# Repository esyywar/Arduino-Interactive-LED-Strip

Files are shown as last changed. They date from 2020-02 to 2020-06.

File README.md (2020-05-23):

# Arduino-Interactive-LED-Strip

This project features the hardware and software development of a multi-function LED strip controller!

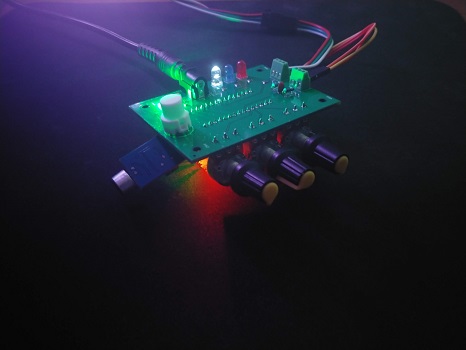
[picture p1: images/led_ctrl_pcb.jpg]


The light strip has 3 different modes:
1. HSV Static Colour Set
2. Patterned Light Show
3. Music Wave Visualizer

User can switch between the 3 modes by pushing a button. In each mode, parameters can be adjusted by turning the 3 potentiometer knobs.

Here are the functions of each knob in each mode:

| Mode  | Knob 1 | Knob 2 | Knob 3 |
| --- | ---- | ---- | ---- |
| HSV Static Colour Set | Hue | Saturation | Brightness |
| Patterned Light Show | Colour Pattern | Scramble Effect | Brightness |
| Music Wave Visualizer | Wave Point Source | Volume Sensitivity | Brightness |

Folders in the repository are organized as follows:

## Firmware

The arduino nano code for this controller. Simple code using FastLED library and interrupts for switching modes.

## PCB-Design

PCB designed in KiCAD to recreate this controller
Can be assembled for about 40 - 80 CAD depending on how much you spend for PCB fabrication and the LED strip.

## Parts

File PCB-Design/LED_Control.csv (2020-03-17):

Comment | Designator | Footprint | LCSC | LCSC
Arduino_Nano_v3.x | A1 | Module:Arduino_Nano
0.1uF | C1,C2 | Capacitor_SMD:C_0603_1608Metric |  | C14663
100uF | C3 | Capacitor_Tantalum_SMD:CP_EIA-3528-15_AVX-H |  | C16133
0.1uF | C4 | Capacitor_THT:C_Disc_D3.4mm_W2.1mm_P2.50mm
BLUE LED | D1 | LED_THT:LED_D5.0mm
RED LED | D2 | LED_THT:LED_D5.0mm
WHITE LED | D3 | LED_THT:LED_D5.0mm
GREEN LED | D4 | LED_SMD:LED_0805_2012Metric |  | C63855
5V 5A Power | J1 | PJ-002AH:CUI_PJ-002AH
TO WS2812B LED STRIP | J2 | TerminalBlock_TE-Connectivity:TerminalBlock_TE_282834-3_1x03_P2.54mm_Horizontal
Sound Sensor | J3 | TerminalBlock_TE-Connectivity:TerminalBlock_TE_282834-3_1x03_P2.54mm_Horizontal
10k | R1 | Resistor_SMD:R_0805_2012Metric |  | C17414
330 | R5,R3,R4,R2 | Resistor_SMD:R_0805_2012Metric |  | C17630
300 | R6 | Resistor_SMD:R_0805_2012Metric |  | C17617
100k | R7 | Resistor_THT:R_Axial_DIN0204_L3.6mm_D1.6mm_P5.08mm_Horizontal
10k | R8 | Resistor_THT:R_Axial_DIN0204_L3.6mm_D1.6mm_P5.08mm_Horizontal
100k | RV1,RV3,RV2 | Custom Footprint:Potentiometer_4mm_Pitch
SW_Push_Dual | SW1 | Custom Footprint:Push_Button_Switch

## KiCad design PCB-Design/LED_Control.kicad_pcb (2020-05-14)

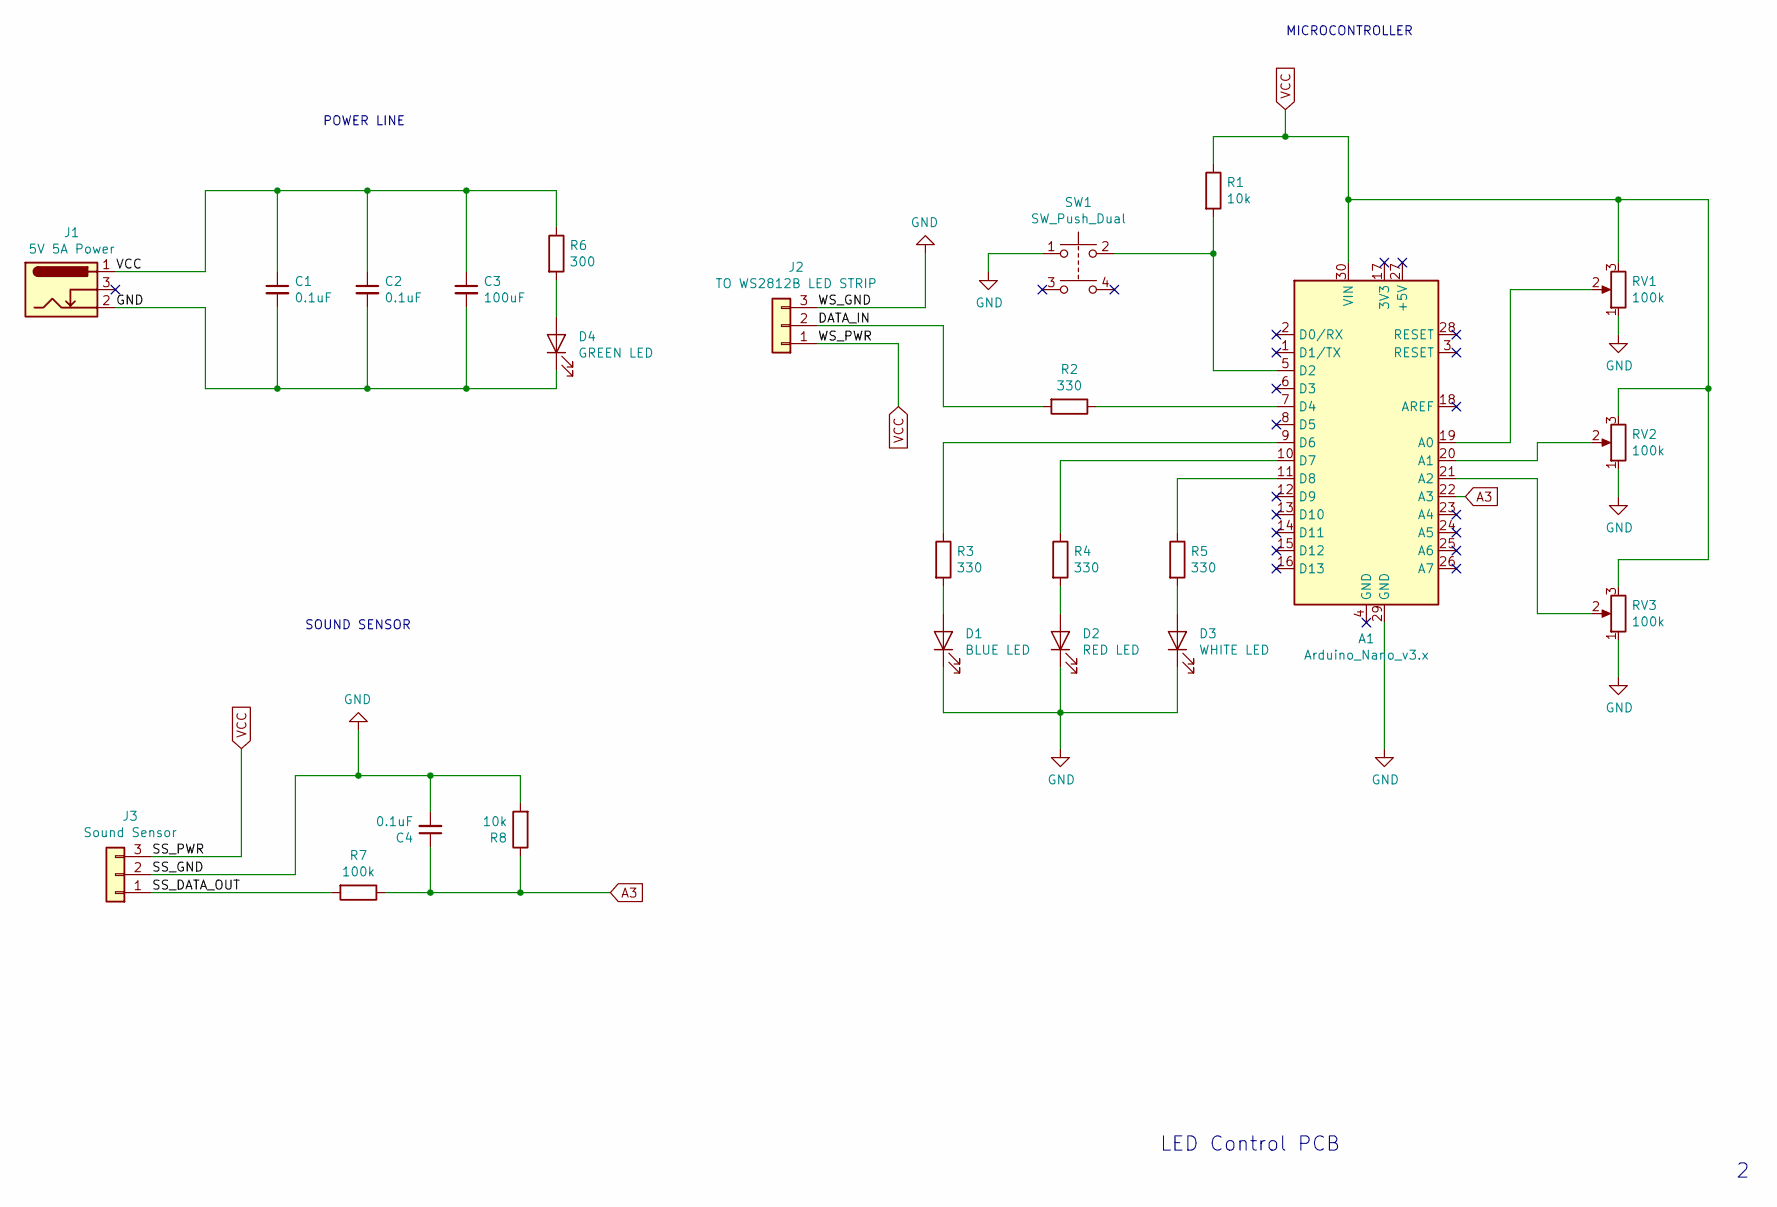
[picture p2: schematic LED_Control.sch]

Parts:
A1: Arduino_Nano_v3.x; Arduino_Nano
C1: 0.1uF; C_0603_1608Metric; LCSC C14663
C2: 0.1uF; C_0603_1608Metric; LCSC C15849
C3: 100uF; CP_EIA-3528-15_AVX-H; LCSC C16133
C4: 0.1uF; C_Disc_D3.4mm_W2.1mm_P2.50mm
D1: BLUE LED; LED_D5.0mm
D2: RED LED; LED_D5.0mm
D3: WHITE LED; LED_D5.0mm
D4: GREEN LED; LED_0805_2012Metric; LCSC C63855
J1: 5V 5A Power; CUI_PJ-002AH
J2: TO WS2812B LED STRIP; TerminalBlock_TE_282834-3_1x03_P2.54mm_Horizontal
J3: Sound Sensor; TerminalBlock_TE_282834-3_1x03_P2.54mm_Horizontal
R1: 10k; R_0805_2012Metric; LCSC C17414
R2, R3, R4, R5: 330; R_0805_2012Metric; LCSC C17630
R6: 300; R_0805_2012Metric; LCSC C17617
R7: 100k; R_Axial_DIN0204_L3.6mm_D1.6mm_P5.08mm_Horizontal
R8: 10k; R_Axial_DIN0204_L3.6mm_D1.6mm_P5.08mm_Horizontal
RV1, RV2, RV3: 100k; Potentiometer_5.08mm_Pitch
SW1: SW_Push_Dual; Push_Button_Switch

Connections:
/DATA_IN: J2.2, R2.2
/SS_DATA_OUT: J3.1, R7.2
A3: A1.22 (A3), C4.1, R7.1, R8.1
GND: A1.29 (GND), C1.2, C2.2, C3.2, C4.2, D1.1 (K), D2.1 (K), D3.1 (K), D4.1 (K), J1.2, J2.3, J3.2, R8.2, RV1.1, RV2.1, RV3.1, SW1.1
unnamed: A1.5 (D2), R1.2, SW1.2
unnamed: A1.7 (D4), R2.1
unnamed: A1.9 (D6), R3.1
unnamed: A1.10 (D7), R4.1
unnamed: A1.11 (D8), R5.1
unnamed: A1.19 (A0), RV1.2
unnamed: A1.20 (A1), RV2.2
unnamed: A1.21 (A2), RV3.2
unnamed: D1.2 (A), R3.2
unnamed: D2.2 (A), R4.2
unnamed: D3.2 (A), R5.2
unnamed: D4.2 (A), R6.2
VCC: A1.30 (VIN), C1.1, C2.1, C3.1, J1.1, J2.1, J3.3, R1.1, R6.1, RV1.3, RV2.3, RV3.3

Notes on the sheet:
MICROCONTROLLER
SOUND SENSOR
POWER LINE
LED Control PCB

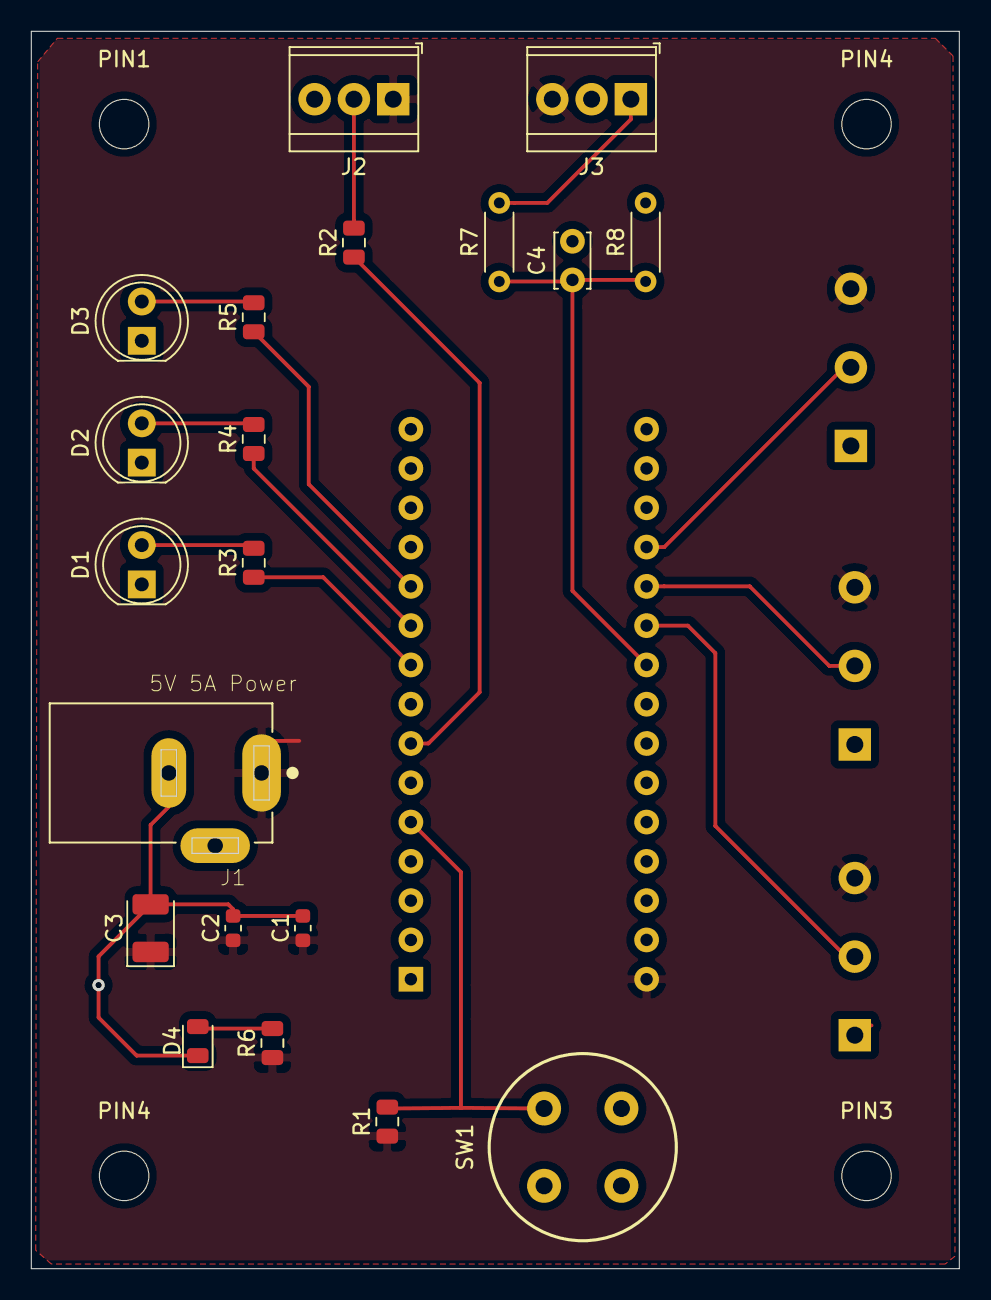
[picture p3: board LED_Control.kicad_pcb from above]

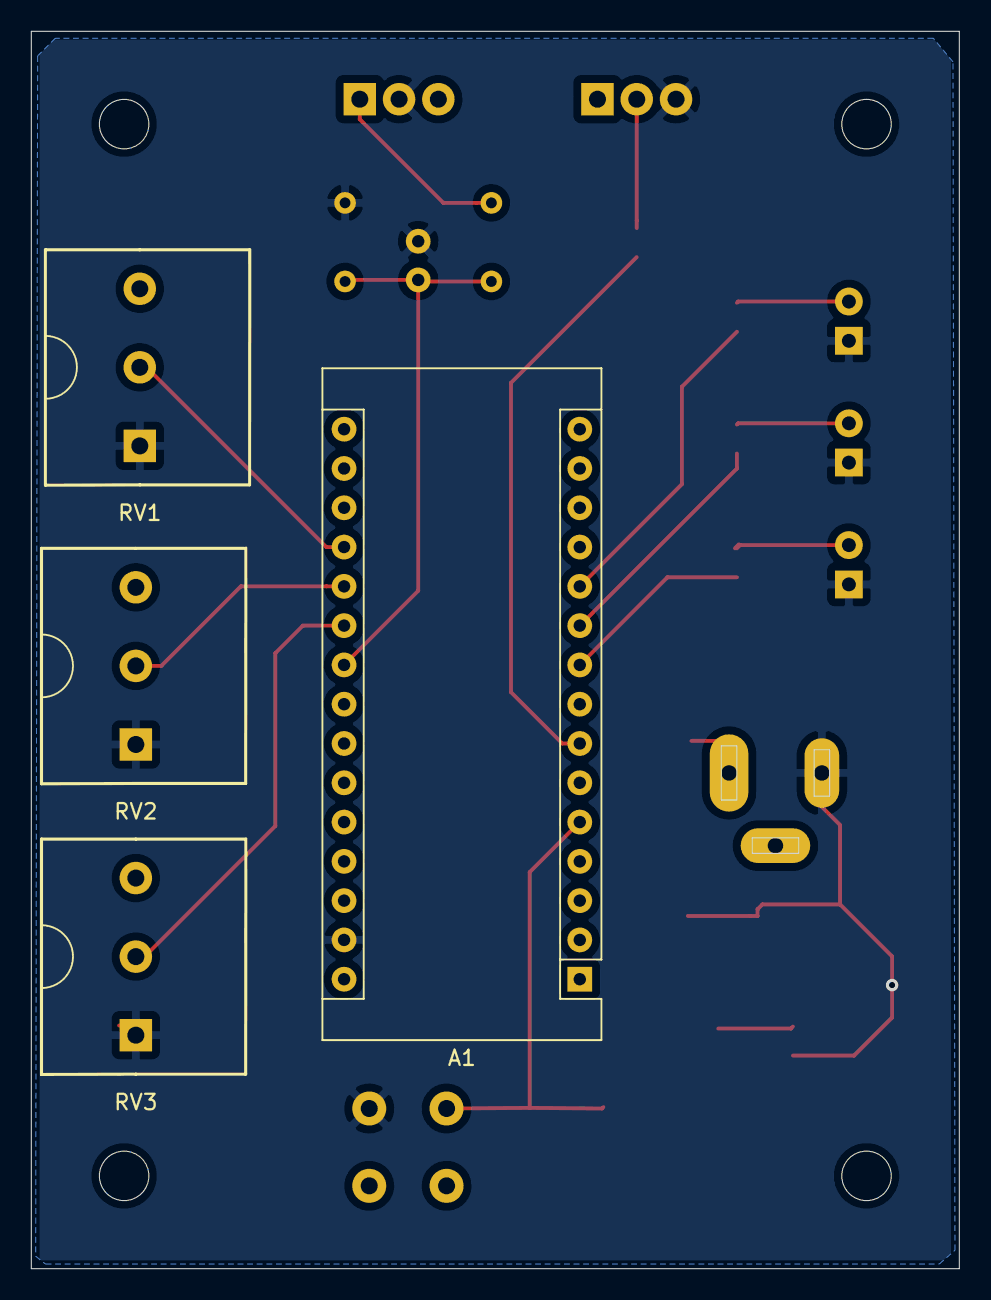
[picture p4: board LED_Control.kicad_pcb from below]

Board: 2 copper layers, 60.0 x 80.0 mm, 28 parts (4 on the bottom side), 17 nets.

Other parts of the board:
PIN1, PIN3, PIN4, PIN4#2: M3 HOLE; MountingHole_3.2mm_M3

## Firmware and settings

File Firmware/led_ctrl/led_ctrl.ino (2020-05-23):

/* LED Strip Controller
 * By: Rahul Eswar
 * Date: October 19, 2019

 * This program is made for on the fly manual control of the WS2812B LED lightstrip.
 * The user can control and configure the LED settings with 3 potentiometer knobs and 1 button
 * The button works to change modes between: HSV colour set, patterned light show and music visualization
 * Knobs control different settings depending on the mode set (e.g. colour in colour set mode, frequency focus in music mode etc.)
 */

// FastLED library definitions
#include <FastLED.h>
#define LED_PIN     4
#define NUM_LEDS    111
#define BRIGHTNESS  64
#define CONTROLS    3
#define LED_TYPE    WS2811
#define COLOR_ORDER GRB
CRGB leds[NUM_LEDS];

// update rate
#define UPDATES_PER_SECOND 100

// number of modes to cycle
#define NUM_MODES 3

// change mode button pin to attach interrupt
#define BTN_PIN 2

// maximum analog reading from sound sensor (sensor read out is after 10k/100k voltage divider and therefore 1023/11=93) - Experimentally observed highs of 97
#define SENSOR_MAX 97

// user input control pins
uint8_t potReadPin[] = {0, 1, 2};

// pin to read from sound sensor
const uint8_t sensorPin = A3;

// variable to store 10 bit value from sound sensor
uint16_t sensorValue;

// declare initial mode
uint8_t mode = 0;

// pins used for LED mode indication
const uint8_t modeLEDs[NUM_MODES] = {6, 7, 8};

// for the interrupt function
volatile byte state = NUM_MODES;

CRGBPalette16 currentPalette;
TBlendType    currentBlending;


// structure for storing the 3 mapped user inputs
typedef struct {
  uint16_t inputA;
  uint16_t inputB;
  uint16_t inputC;
} LEDSettings;

// global variable to store user inputs
LEDSettings userInput;

// Defining custom palette of Raptors colours!
const TProgmemPalette16 TorontoRaptors_p PROGMEM =
{
    CRGB::DarkRed,
    CRGB::DarkRed,
    CRGB::DarkRed,
    CRGB::DarkRed,
    CRGB::DarkRed,
    
    CRGB::DarkViolet,
    CRGB::DarkViolet,
    CRGB::DarkViolet,

    CRGB::Snow,
    CRGB::Snow,
    CRGB::Snow,
    CRGB::Snow,
    
    CRGB::Purple, 
    CRGB::Purple,
    CRGB::Purple,
    CRGB::Purple   
};


// Defining custom palette of Lakers colours!
const TProgmemPalette16 Lakers_p PROGMEM =
{
    CRGB::Yellow,
    CRGB::Yellow,
    CRGB::Yellow,
    CRGB::Yellow,
    
    CRGB::Purple,
    CRGB::Purple,
    CRGB::Purple,
    CRGB::Purple,
    
    CRGB::White,
    CRGB::White,
    
    CRGB::Yellow,
    CRGB::Yellow,
    CRGB::Yellow,
    CRGB::Purple,
    CRGB::Purple,
    CRGB::Purple
};


// Defining custom palette of the India flag
const TProgmemPalette16 India_p PROGMEM =
{
    CRGB::Orange,
    CRGB::Orange,
    CRGB::Gray,
    CRGB::Green,
    CRGB::Green,
    
    CRGB::Blue,
    CRGB::Blue,
    CRGB::Gray,
    
    CRGB::Green,
    CRGB::Green,
    CRGB::Gray,
    CRGB::Gray,
    CRGB::Orange,
    CRGB::Orange,
    
    CRGB::Gray,
    CRGB::Gray
};


void setup() {
  // power-up safety delay
  delay(1500);
  
  // data rate
  Serial.begin(9600);

  // FastLED library set-up
  FastLED.addLeds<WS2812, LED_PIN, COLOR_ORDER>(leds, NUM_LEDS).setCorrection( TypicalLEDStrip );
  FastLED.setBrightness(64);

  // pin declarations for interrupt
  pinMode (BTN_PIN, INPUT_PULLUP);

  // set pins for LED mode indicators as output
  for (int i= 0; i < NUM_MODES; i++)
  {
    pinMode (modeLEDs[modeLEDs[0] + i], OUTPUT);
  }

  // attaching interrupt used for mode switch on button press
  attachInterrupt(digitalPinToInterrupt(BTN_PIN), changeMode, FALLING);

  // initialization of colour palette color breathe mode
  currentPalette = RainbowColors_p;
  currentBlending = LINEARBLEND;  
}


void loop() {
  // calculate the active state
  mode = state % NUM_MODES;

  // change LED to show user what mode we are in
  modeIndicateLED(mode);

  // execute the operation for active mode
  executeMode(mode);

  FastLED.show();
  FastLED.delay(1000 / UPDATES_PER_SECOND);
}


// turns active mode LED on and the rest are off (indicates to user the mode we are in)
void modeIndicateLED (uint8_t mode) {
   for (int i = 0; i < NUM_MODES; i++) 
   {
      if (i == mode)
      {
        digitalWrite(modeLEDs[i], HIGH);
      }
      else
      {
        digitalWrite(modeLEDs[i], LOW);
      }
   }
}


// calls the required function based on active mode
void executeMode(uint8_t mode) {

  // for start index in color pallete mode
  static uint16_t startIndex = 1;

  switch (mode) 
  {
    case 0:
      staticColourSet();
      break;
    case 1:
      startIndex++; // motion speed
      lightShow(startIndex);
      break;
    case 2:
      musicVisualizer();
      break;
    default:
      staticColourSet();
  }
}


// interrupt function to run on button press
void changeMode() {
  // reason for this condition is to correct hardware issue of button double triggering...
  static unsigned long lastInterrupt;
  
  if (millis() - lastInterrupt > 250)
  {
    state++;  
    lastInterrupt = millis();
  }
}


// returns mapped inputs from input knobs in form of structure 'userSettings'
void mapInputs (LEDSettings *newSettings, uint16_t range1, uint16_t range2, uint16_t range3) {

  // read and map the values
  newSettings->inputA = map(analogRead(potReadPin[0]), 0, 1023, 0, range1);
  newSettings->inputB = map(analogRead(potReadPin[1]), 0, 1023, 0, range2);
  newSettings->inputC = map(analogRead(potReadPin[2]), 0, 1023, 0, range3);
}


// MODE:0 - takes user input and maps to HSV colours
void staticColourSet() {
  // create variable of structure 'userSettings' and fill with mapped values
  mapInputs(&userInput, 255, 255, 255);

  

  for (int i = 0; i < NUM_LEDS; i++)
  {
      leds[i] = CHSV(userInput.inputA, userInput.inputB, userInput.inputC);
  }
}


// MODE:1 - goes through patterns of changing LEDs from the loaded palette
void lightShow(uint16_t startIndex) {

  mapInputs(&userInput, 6, 255, 255);

  // first knob is adjusted to choose the colour palette
  // second knob is manipulate motion speed
  // third knob assigns brightness

  switch (userInput.inputA)
  {
    case 0:
      currentPalette = RainbowColors_p;
      break;
    case 1:
      currentPalette = OceanColors_p;
      break;
    case 2:
      currentPalette = ForestColors_p;
      break;
    case 3:
      currentPalette = TorontoRaptors_p;
      break;
    case 4:
      currentPalette = Lakers_p;
     break;
    case 5 ... 6:
      currentPalette = India_p;
     break;
    default:
      currentPalette = RainbowColors_p;
  }
  
  // write to LEDS as required
  for (int i = 0; i < NUM_LEDS; i++) 
  {
      leds[i] = ColorFromPalette(currentPalette, startIndex, userInput.inputC, currentBlending);
      startIndex += userInput.inputB;
  }
}


// MODE:2 - real time music visualizer (can configure origin LED, sensitivity and rate of colour change)
void musicVisualizer() {

  // Potentiometer 1 is origin LED number, 2 is the sensor threshold value to show colour, 3 is minimum value for brightness range
  mapInputs(&userInput, NUM_LEDS - 1, SENSOR_MAX, 254);  // second map value due to a 1:10 pull down resistor on sensor pin

  // initialize the colour which will be swept through
  static uint8_t colour = 1;

  colour++;
 
  sensorValue = analogRead(sensorPin);

  Serial.println(sensorValue);

  // colour the first pixel according to the live sound
  colourOriginPixel(sensorValue, colour, userInput.inputA, userInput.inputB, userInput.inputC);  

  // propagate the colour wave in 2 directions from origin
  pointSourceWave(userInput.inputA);  
}


// colour pixels at the chosen source on LED strip for music visualizer
void colourOriginPixel (uint16_t sensorValue, uint8_t colour, uint16_t origin, uint16_t threshold, uint8_t minBrightness) {
  if (sensorValue > threshold)
  {
    leds[origin] = CHSV(colour, 255, map(sensorValue, 0, SENSOR_MAX, minBrightness, 255));
  }
  else 
  {
    leds[origin].setRGB(0, 0, 0);
  }
}


// function takes an origin point LED and propagates the wave in both directions away from source for music visualizer
void pointSourceWave (uint16_t origin) {
  for (int i = 0; i < origin; i++) 
  {
    leds[i] = leds[i + 1];    
  }
  
  for (int i = NUM_LEDS - 1; i > origin; i--) 
  {
    leds[i] = leds[i - 1];
  }
}

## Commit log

2020-01-25 programs merged but bug with colour interval in visualizer
    [led_ctrl.ino]
2020-01-26 memory issue identified - variable sizes optimized
    [led_ctrl.ino]
2020-01-26 bug found with mode change - save working version
    [led_ctrl.ino]
2020-01-26 all bugs resolved and tested
    [led_ctrl.ino]
2020-01-28 circuit schematic complete
    [LED Control.sch]
2020-01-30 PCB footprints added
    [LED Control.sch]
2020-02-08 connectors selected and footprints updated
    [LED Control.kicad_pcb, LED Control.sch]
2020-02-08 capacitor footprints changed to axial
    [LED Control.kicad_pcb, LED Control.sch]
2020-02-08 Rs, Cs, LED updated for SMT
    [LED Control.kicad_pcb, LED Control.sch]
2020-02-11 pull up/down resistors added
    [LED Control.sch]
2020-02-11 pcb layout created
    [LED Control.kicad_pcb, LED Control.sch]
2020-02-11 pcb size made 60x60
    [LED Control.kicad_pcb, LED Control.sch]
2020-02-12 firmware adjusted for voltage divider and filter at sound sensor
2020-02-13 firmware bug found and corrected
    [led_ctrl.ino]
2020-02-24 edge cuts and M3 mounting holes added
    [LED Control.kicad_pcb, LED Control.sch]
2020-02-26 microcontroller moved to bottom side
    [LED Control.kicad_pcb]
2020-02-28 power, gnd planes and traces
    [LED Control.kicad_pcb, LED Control.sch]
2020-02-29 PCB completed
    [LED Control.kicad_pcb, LED Control.sch]
2020-02-29 gerbers generated
    [LED Control-B_Cu.gbr, LED Control-B_Mask.gbr, LED Control-B_SilkS.gbr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]
2020-02-29 CPL and BOM generated
    [LED_Control-B_Cu.gbr, LED_Control-B_Mask.gbr, LED_Control-B_Paste.gbr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]
2020-03-01 CPL and BOM file format set
    [LED_Control-B_Cu.gbr, LED_Control-B_Mask.gbr, LED_Control-B_Paste.gbr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]
2020-03-01 final submitted build files
    [LED_Control-B_Cu.gbr, LED_Control-B_Mask.gbr, LED_Control-B_Paste.gbr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]
2020-03-13 potentiometer footprint fixed
    [LED_Control-B_Cu.gbr, LED_Control-B_Mask.gbr, LED_Control-B_Paste.gbr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]
2020-03-13 origin select for music vis. fix
    [led_ctrl.ino]
2020-03-17 Rev 2. alterations to PCB
    [LED_Control.csv, LED_Control.kicad_pcb, LED_Control.sch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]
2020-05-14 firmware potentiometer range corrected for pcb impedances
    [LED_Control.kicad_pcb]
2020-05-14 adjusted thresholds for pcb impedances
